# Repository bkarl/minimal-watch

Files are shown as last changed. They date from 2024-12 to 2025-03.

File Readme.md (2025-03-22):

# minimal-watch
This repo contains hardware and software for a minimalistic smartwatch. 

## Design goals

* step counter
* battery life of >= one year
* NFC data exchange
* powered by a coin cell
* fits a Casio F-91 W housing
* binary or hex time display using 12 bicolor LEDs
* brightness sensor to dim LEDs

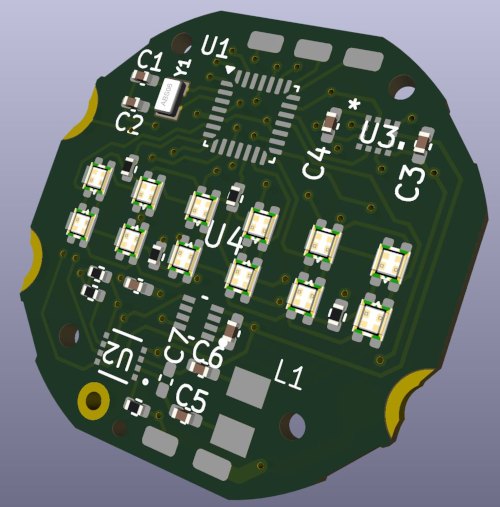
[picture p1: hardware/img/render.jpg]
minimal-watch


## Issues in hw v0.0.1
* swapped SCL/SDA lines
* missing pull up on NFC interrupt line (BOOT0 does not have an internal pull up)
* wakeup sources (BMA400 or NFC) are not connected to WKUP pins so standby mode is not possible
* resistor for green LEDs is too large
* NFC antenna circuit is not working (coil had to be crafted by hand and glued to housing)

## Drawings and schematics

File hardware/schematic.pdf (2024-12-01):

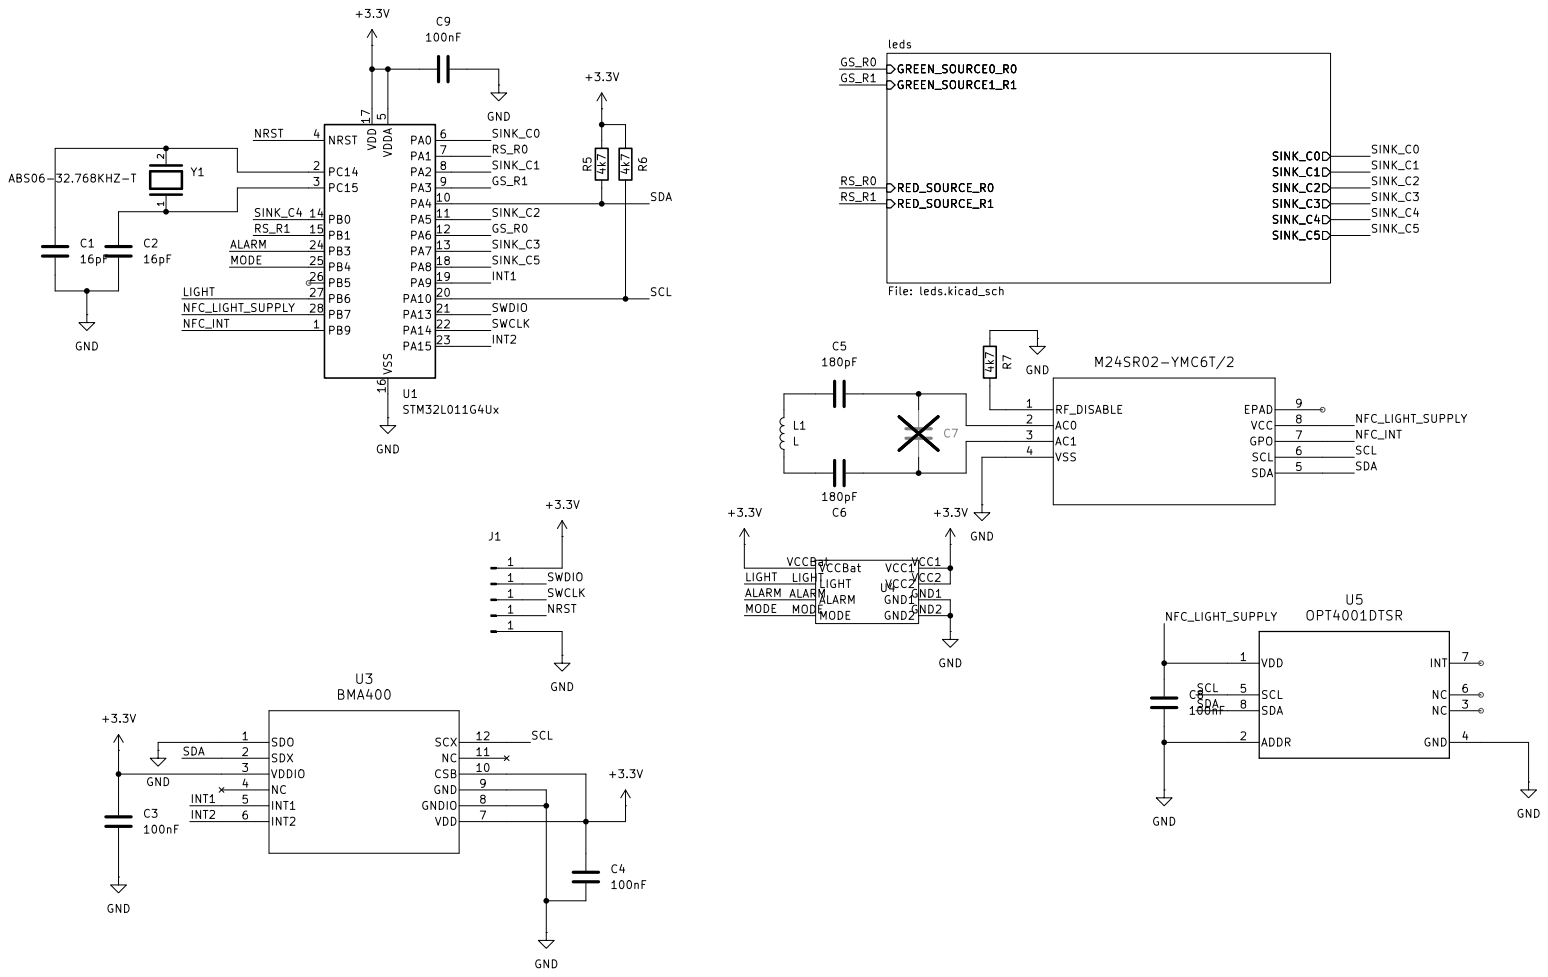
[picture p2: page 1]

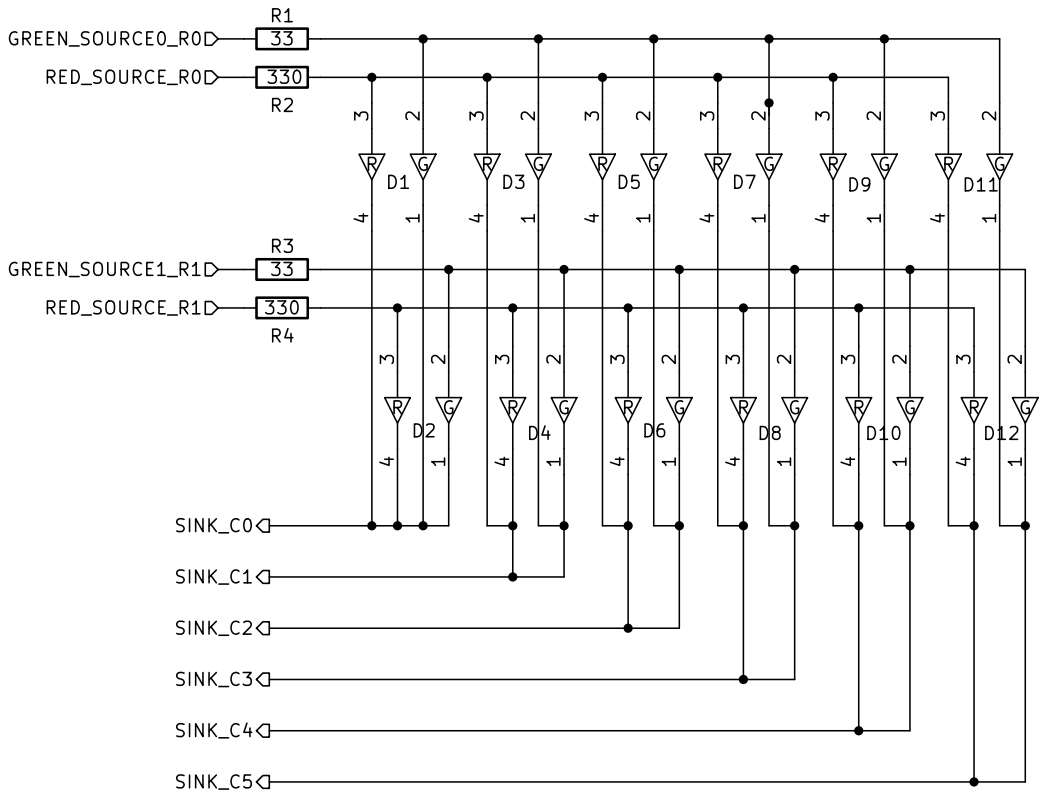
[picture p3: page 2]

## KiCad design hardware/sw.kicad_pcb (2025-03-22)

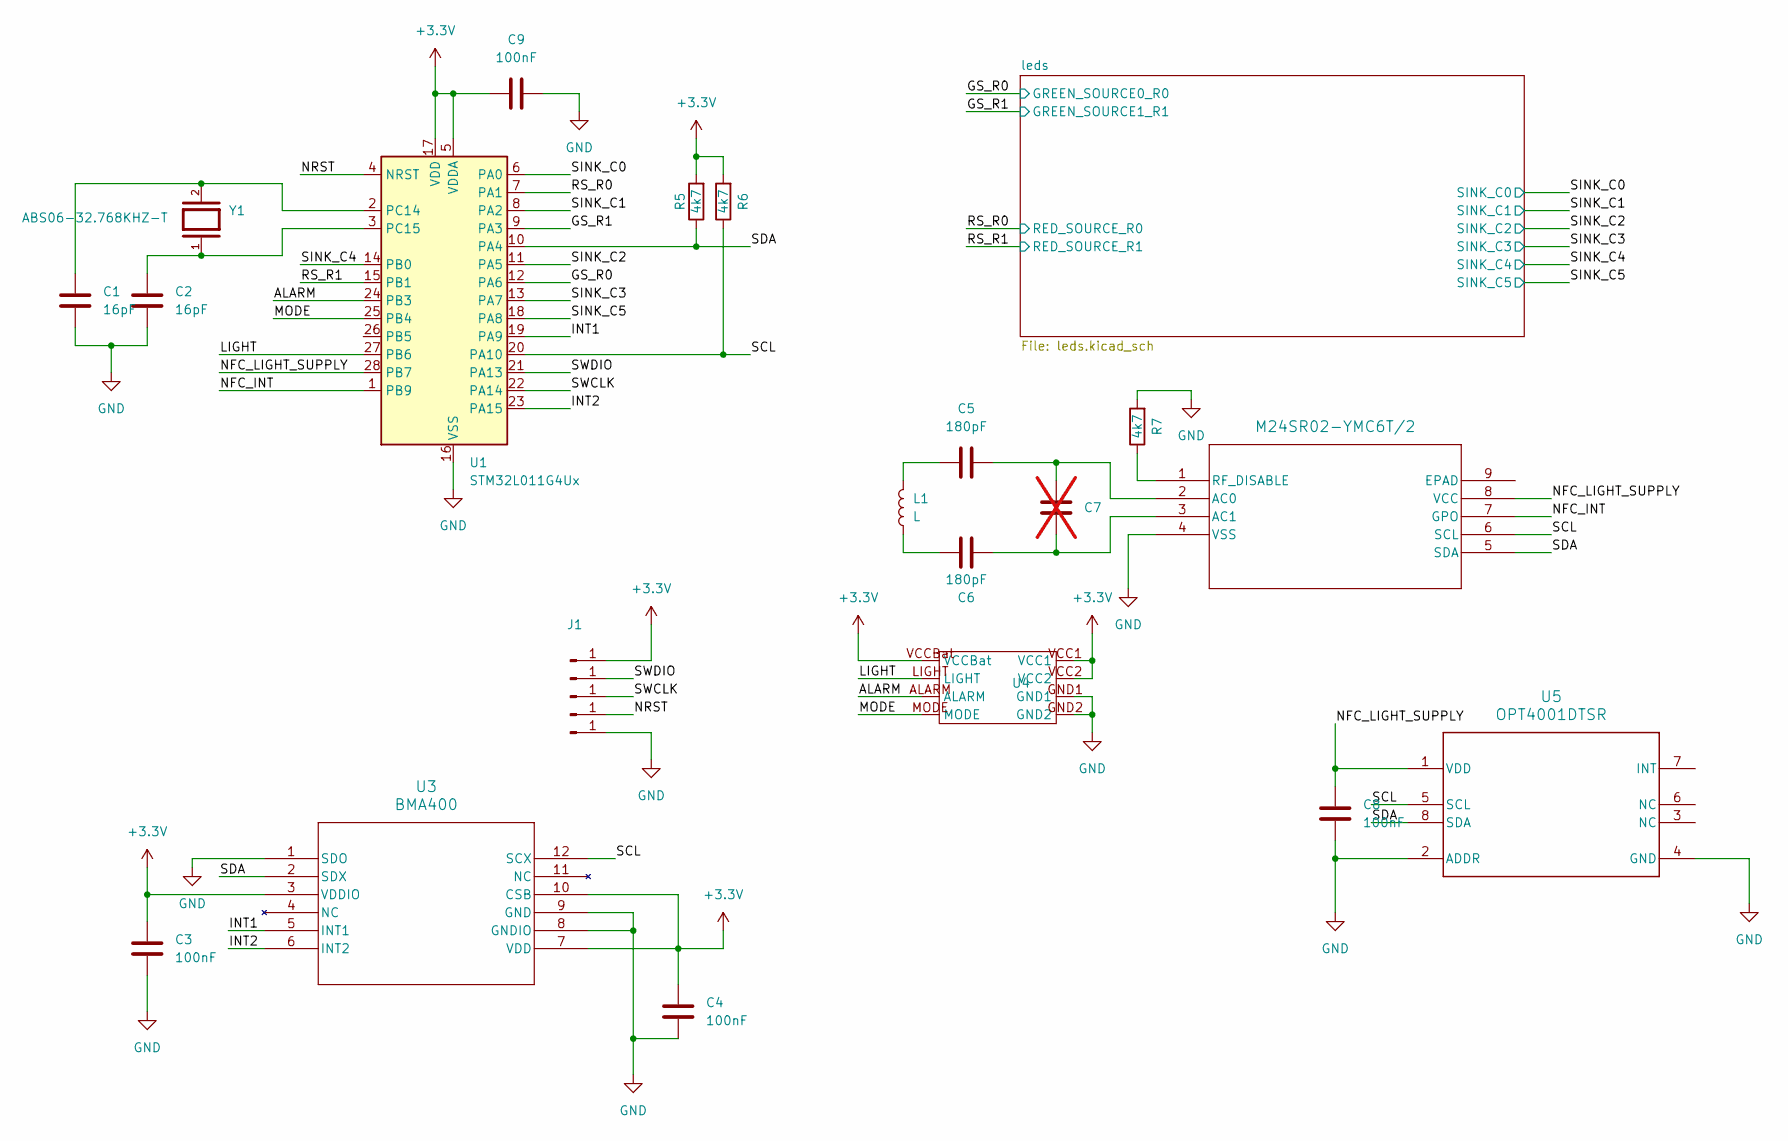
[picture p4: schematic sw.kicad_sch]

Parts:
C1, C2: 16pF; C_0402_1005Metric_Pad0.74x0.62mm_HandSolder
C3, C4, C8, C9: 100nF; C_0402_1005Metric_Pad0.74x0.62mm_HandSolder
C5, C6: 180pF; C_0402_1005Metric_Pad0.74x0.62mm_HandSolder
C7: C_0402_1005Metric_Pad0.74x0.62mm_HandSolder; not fitted
J1, J2, J3, J4, J5: Conn_01x01_Pin; SolderWirePad_1x01_SMD_1x2mm
L1: L; AANI-CH-0029
R5, R6, R7: 4k7; R_0402_1005Metric
U1: STM32L011G4Ux; QFN-28_4x4mm_P0.5mm
U2: M24SR02-YMC6T/2; UFDFPN8_M24SR02_STM
U3: BMA400; QFN_BMA400_BOS
U4: CASIO-F91W-OUTLINE-USB
U5: OPT4001DTSR; DTS0008A-MFG
Y1: ABS06-32.768KHZ-T; XTAL_ABS06-32.768KHZ-T; PARTREV 4/25/2022

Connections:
+3.3V: C3.1, C4.1, C9.1, J1.1, R5.2, R6.2, U1.5 (VDDA), U1.17 (VDD), U3.3 (VDDIO), U3.7 (VDD), U3.10 (CSB), U4.VCC1, U4.VCC2, U4.VCCBat
/ALARM: U1.24 (PB3), U4.ALARM
/GS_R0: U1.12 (PA6); also elsewhere on the board
/GS_R1: U1.9 (PA3); also elsewhere on the board
/INT1: U1.19 (PA9), U3.5 (INT1)
/INT2: U1.23 (PA15), U3.6 (INT2)
/LIGHT: U1.27 (PB6), U4.LIGHT
/MODE: U1.25 (PB4), U4.MODE
/NFC_INT: U1.1 (PB9), U2.7 (GPO)
/NFC_LIGHT_SUPPLY: C8.1, U1.28 (PB7), U2.8 (VCC), U5.1 (VDD)
/NRST: J4.1, U1.4 (NRST)
/RS_R0: U1.7 (PA1); also elsewhere on the board
/RS_R1: U1.15 (PB1); also elsewhere on the board
/SCL: R6.1, U1.20 (PA10), U2.6 (SCL), U3.12 (SCX), U5.5 (SCL)
/SDA: R5.1, U1.10 (PA4), U2.5 (SDA), U3.2 (SDX), U5.8 (SDA)
/SINK_C0: U1.6 (PA0); also elsewhere on the board
/SINK_C1: U1.8 (PA2); also elsewhere on the board
/SINK_C2: U1.11 (PA5); also elsewhere on the board
/SINK_C3: U1.13 (PA7); also elsewhere on the board
/SINK_C4: U1.14 (PB0); also elsewhere on the board
/SINK_C5: U1.18 (PA8); also elsewhere on the board
/SWCLK: J3.1, U1.22 (PA14)
/SWDIO: J2.1, U1.21 (PA13)
GND: C1.1, C2.2, C3.2, C4.2, C8.2, C9.2, J5.1, R7.2, U1.16 (VSS), U2.4 (VSS), U3.1 (SDO), U3.8 (GNDIO), U3.9 (GND), U4.GND1, U4.GND2, U5.2 (ADDR), U5.4 (GND)
unnamed: C5.1, L1.2
unnamed: C6.1, L1.1
unnamed: C1.2, U1.2 (PC14), Y1.2
unnamed: C2.1, U1.3 (PC15), Y1.1
unnamed: C5.2, C7.2, U2.2 (AC0)
unnamed: C6.2, C7.1, U2.3 (AC1)
unnamed: R7.1, U2.1 (RF_DISABLE)

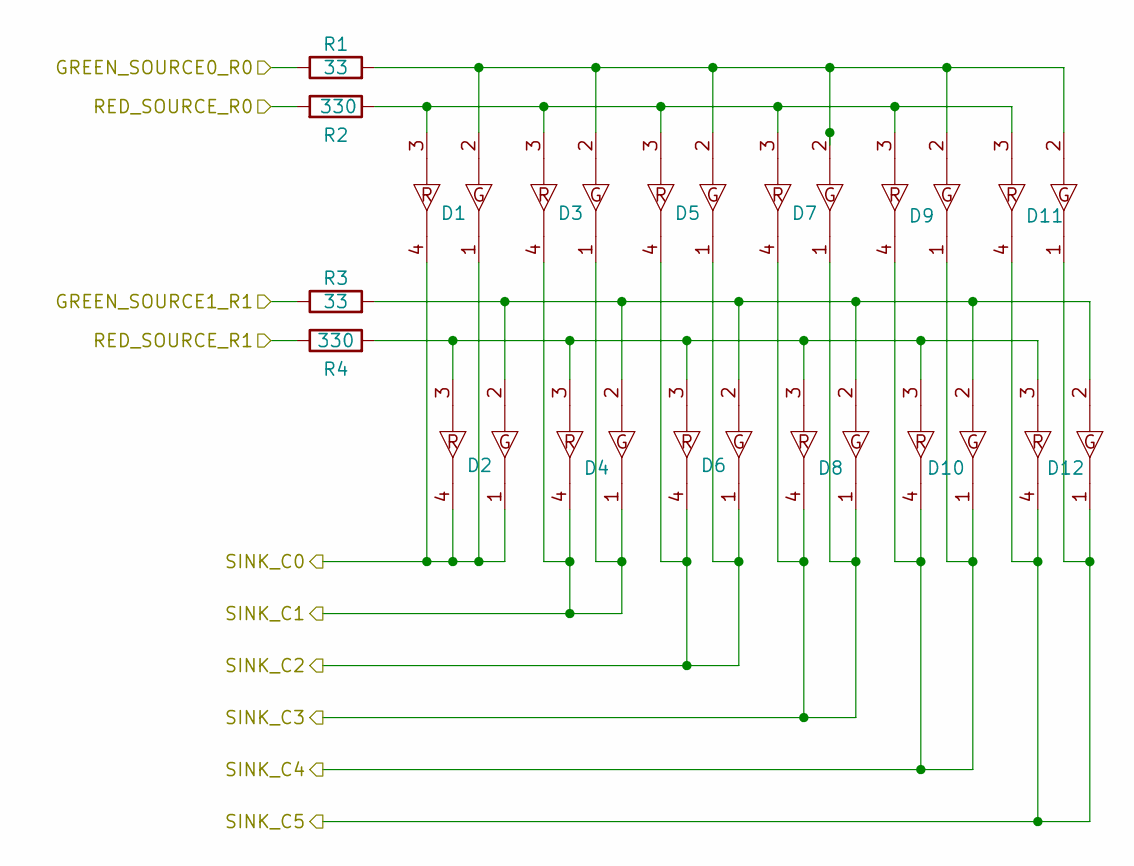
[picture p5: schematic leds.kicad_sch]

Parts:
D1, D2, D3, D4, D5, D6, D7, D8, D9, D10, D11, D12: WL-SBCD_150066RG54050
R1, R3: 33; R_0402_1005Metric
R2, R4: 330; R_0402_1005Metric

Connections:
/GS_R0: R1.1; also elsewhere on the board
/GS_R1: R3.1; also elsewhere on the board
/RS_R0: R2.2; also elsewhere on the board
/RS_R1: R4.1; also elsewhere on the board
/SINK_C0: D1.1, D1.4, D2.1, D2.4; also elsewhere on the board
/SINK_C1: D3.1, D3.4, D4.1, D4.4; also elsewhere on the board
/SINK_C2: D5.1, D5.4, D6.1, D6.4; also elsewhere on the board
/SINK_C3: D7.1, D7.4, D8.1, D8.4; also elsewhere on the board
/SINK_C4: D9.1, D9.4, D10.1, D10.4; also elsewhere on the board
/SINK_C5: D11.1, D11.4, D12.1, D12.4; also elsewhere on the board
unnamed: D1.2, D3.2, D5.2, D7.2, D9.2, D11.2, R1.2
unnamed: D1.3, D3.3, D5.3, D7.3, D9.3, D11.3, R2.1
unnamed: D2.2, D4.2, D6.2, D8.2, D10.2, D12.2, R3.2
unnamed: D2.3, D4.3, D6.3, D8.3, D10.3, D12.3, R4.2

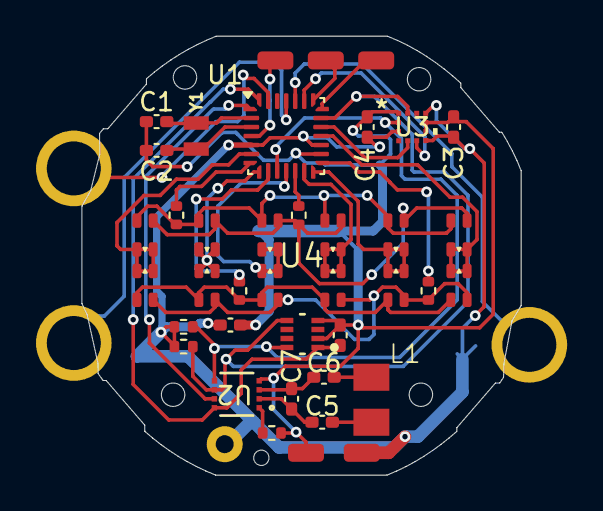
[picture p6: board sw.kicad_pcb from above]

Board: 2 copper layers, 24.4 x 24.4 mm, 40 parts (0 on the bottom side), 35 nets.

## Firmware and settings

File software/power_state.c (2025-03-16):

#include "power_state.h"
#include "settings.h"

volatile bool enter_sleep_mode = false;

void power_enter_stop_mode()
{
    //power_deinit_gpios();

    /*
    RCC_OscInitTypeDef RCC_OscInitStruct = {0};
    RCC_OscInitStruct.OscillatorType = RCC_OSCILLATORTYPE_LSE;
    RCC_OscInitStruct.LSEState = RCC_LSE_ON;
    if (HAL_RCC_OscConfig(&RCC_OscInitStruct) != HAL_OK)
    {
      Error_Handler();
    }
    */
    __HAL_PWR_CLEAR_FLAG(PWR_FLAG_WU);
    HAL_SuspendTick();
    HAL_PWR_EnterSTOPMode(PWR_LOWPOWERREGULATOR_ON, PWR_STOPENTRY_WFI);
}

void power_enable_light_nfc() {
  __HAL_RCC_GPIOB_CLK_ENABLE();

  GPIO_InitTypeDef GPIO_InitStruct = {0};

  GPIO_InitStruct.Pin = GPIO_PIN_NFC_LIGHTSENSOR_SUPPLY;
  GPIO_InitStruct.Mode = GPIO_MODE_OUTPUT_PP;
  GPIO_InitStruct.Speed = GPIO_SPEED_FREQ_VERY_HIGH;
  GPIO_InitStruct.Pull = GPIO_NOPULL;
  HAL_GPIO_Init(GPIO_PORT_NFC_LIGHTSENSOR_SUPPLY, &GPIO_InitStruct);
  HAL_GPIO_WritePin(GPIO_PORT_NFC_LIGHTSENSOR_SUPPLY, GPIO_PIN_NFC_LIGHTSENSOR_SUPPLY, GPIO_PIN_SET);
}

void power_disable_light_nfc() {
  __HAL_RCC_GPIOB_CLK_ENABLE();

  GPIO_InitTypeDef GPIO_InitStruct = {0};

  GPIO_InitStruct.Pin = GPIO_PIN_NFC_LIGHTSENSOR_SUPPLY;
  GPIO_InitStruct.Mode = GPIO_MODE_OUTPUT_PP;
  GPIO_InitStruct.Speed = GPIO_SPEED_FREQ_VERY_HIGH;
  GPIO_InitStruct.Pull = GPIO_NOPULL;
  HAL_GPIO_Init(GPIO_PORT_NFC_LIGHTSENSOR_SUPPLY, &GPIO_InitStruct);
  HAL_GPIO_WritePin(GPIO_PORT_NFC_LIGHTSENSOR_SUPPLY, GPIO_PIN_NFC_LIGHTSENSOR_SUPPLY, GPIO_PIN_RESET);
}

void power_leave_stop_mode()
{
  HAL_ResumeTick();
  enter_sleep_mode = false;
}

void power_deinit_gpios() {
  GPIO_InitTypeDef GPIO_InitStruct = {0};

  __HAL_RCC_GPIOB_CLK_ENABLE();
  __HAL_RCC_GPIOC_CLK_ENABLE();
  __HAL_RCC_GPIOA_CLK_ENABLE();

  GPIO_InitStruct.Pin = GPIO_PIN_All;
  GPIO_InitStruct.Mode = GPIO_MODE_ANALOG;
  GPIO_InitStruct.Speed = GPIO_SPEED_FREQ_VERY_HIGH;
  GPIO_InitStruct.Pull = GPIO_NOPULL;
  HAL_GPIO_Init(GPIOB, &GPIO_InitStruct);
  HAL_GPIO_Init(GPIOA, &GPIO_InitStruct);

  __HAL_RCC_GPIOA_CLK_DISABLE();
  __HAL_RCC_GPIOB_CLK_DISABLE();
  __HAL_RCC_GPIOC_CLK_DISABLE();
}

void power_init_timeout_counter() {
  __HAL_RCC_LPTIM1_CLK_ENABLE();

  HAL_NVIC_SetPriority(LPTIM1_IRQn, 0, 0);
  HAL_NVIC_EnableIRQ(LPTIM1_IRQn);
  LPTIM1->CR = 0;
  LPTIM1->IER = LPTIM_IER_CMPMIE;
  LPTIM1->CFGR = LPTIM_CFGR_PRESC;
  LPTIM1->CR = LPTIM_CR_ENABLE;
  LPTIM1->ARR = (32768 / 128) * DISPLAY_TIMEOUT_SECONDS + 1;
  LPTIM1->CMP = (32768 / 128) * DISPLAY_TIMEOUT_SECONDS;
  LPTIM1->CR = LPTIM_CR_ENABLE | LPTIM_CR_CNTSTRT;
}

void power_stop_timeout_counter() {
  LPTIM1->CR = 0;
  __HAL_RCC_LPTIM1_CLK_DISABLE();
}

void power_reset_timeout_counter() {
  LPTIM1->CR = 0;
  LPTIM1->CR = LPTIM_CR_ENABLE | LPTIM_CR_CNTSTRT;
}

void power_timeout_counter_elapsed()
{
  power_stop_timeout_counter();
  enter_sleep_mode = true;
}

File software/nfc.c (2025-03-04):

#include "nfc.h"
#include "power_state.h"

void nfc_copy_step_ctr_payload(uint8_t *dst_buffer, RTC_DateTypeDef *sDate, uint32_t n_steps);
void nfc_write_data_to_memory(uint8_t *data, uint8_t offset, uint8_t len);
void nfc_set_int_to_wip_mode();

void init_nfc() {
    power_enable_light_nfc();
    uint8_t rdata_out[255];
    c_apdu_r response = {
        .data = rdata_out
    };

    uint8_t data[] = {0xD2, 0x76, 0x00, 0x00, 0x85, 0x01, 0x01};
    c_apdu_t select_ndef_tag_application = {
        .PCB = NFC_PCB_BYTE,
        .CLA = 0,
        .INS = NFC_INS_SELECT_FILE,
        .P1 = 0x04,
        .P2 = 0x00,
        .LC = 0x07,
        .data = data,
        .LE = 0
    };

    uint8_t data_ndef_select[] = {0x00, 0x01};

    c_apdu_t select_ndef_file = {
        .PCB = NFC_PCB_BYTE,
        .CLA = 0,
        .INS = NFC_INS_SELECT_FILE,
        .P1 = 0x00,
        .P2 = 0x0C,
        .LC = 0x02,
        .data = data_ndef_select,
        .LE = 0
    };

    nfc_init_crc_engine();
    do {
        i2c_write_register(NFC_ADDRESS, NFC_GET_I2C_SESSION, NULL, 0);

        HAL_Delay(NFC_WAIT_MS_AFTER_CMD);

        nfc_send_apdu_p(&select_ndef_tag_application, true);
        nfc_read_apdu_r(&response, select_ndef_tag_application.LE);
    } while (response.SW1 != 0x90);

    //nfc_set_int_to_wip_mode();

    nfc_send_apdu_p(&select_ndef_file, false);
    nfc_read_apdu_r(&response, select_ndef_file.LE);
}

void nfc_set_int_to_wip_mode() {
    c_apdu_r response;

    uint8_t data_ndef_select[] = {0xE1, 0x01};

    c_apdu_t select_system_file = {
        .PCB = NFC_PCB_BYTE,
        .CLA = 0,
        .INS = NFC_INS_SELECT_FILE,
        .P1 = 0x00,
        .P2 = 0x0C,
        .LC = 0x02,
        .data = data_ndef_select,
        .LE = 0
    };

    nfc_send_apdu_p(&select_system_file, false);
    nfc_read_apdu_r(&response, select_system_file.LE);

    uint8_t system_file[0x11];
    nfc_read_data_from_memory(system_file, 0, sizeof(system_file));

    uint8_t pw[16] = {0};

    c_apdu_t verify_file = {
        .PCB = NFC_PCB_BYTE,
        .CLA = 0,
        .INS = 0x20,
        .P1 = 0x00,
        .P2 = 0x03,
        .LC = 0x10,
        .data = pw,
        .LE = 0
    };

    nfc_send_apdu_p(&verify_file, false);
    nfc_read_apdu_r(&response, verify_file.LE);

    uint8_t gpo_byte = 0x30;
    nfc_write_data_to_memory(&gpo_byte, 4, 1);
    nfc_read_data_from_memory(&gpo_byte, 4, 1);
    
    return;
}

void deinit_nfc() {
    power_disable_light_nfc();
}

uint8_t nfc_read_total_ndef_length() {
    uint8_t len[2];

    nfc_read_data_from_memory(len, 0, sizeof(len));
    uint8_t total_len = len[1];
    return total_len;
}

void nfc_read_data_from_memory(uint8_t *dst, uint8_t offset, uint8_t len) {
    c_apdu_r response = {.data = dst};

    c_apdu_t read_binary = {
        .PCB = NFC_PCB_BYTE,
        .CLA = 0,
        .INS = NFC_INS_READ_BINARY,
        .P1 = 0x00,
        .P2 = offset,
        .LC = 0x00,
        .data = 0,
        .LE = len
    };

    nfc_send_apdu_p(&read_binary, true);
    nfc_read_apdu_r(&response, read_binary.LE);
    return;
}


bool nfc_read_timestamp_record(RTC_TimeTypeDef *sTime, RTC_DateTypeDef *sDate) {
    uint8_t rdata_out[255];

    c_apdu_r response = {
        .data = rdata_out
    };

    c_apdu_t read_binary = {
        .PCB = NFC_PCB_BYTE,
        .CLA = 0,
        .INS = NFC_INS_READ_BINARY,
        .P1 = 0x00,
        .P2 = 0x02,
        .LC = 0x00,
        .data = 0,
        .LE = 0x02
    };

    uint8_t total_len = nfc_read_total_ndef_length();

    if (total_len > NFC_STEP_RECORD_MIN_LENGTH || total_len == 0)
        return false;

    read_binary.P2 = 2;
    read_binary.LE = total_len;

    nfc_send_apdu_p(&read_binary, true);
    nfc_read_apdu_r(&response, read_binary.LE);
    external_type_ndef_record_t *timestamp_record = (external_type_ndef_record_t*)response.data;
    size_t offset_to_payload = timestamp_record->type_len + NUM_HEADER_BYTES_IN_NFC_PAYLOAD;

    timestamp_record->payload = &response.data[offset_to_payload];
    sDate->Year = timestamp_record->payload[OFFSET_TO_YEAR];
    sDate->Month = timestamp_record->payload[OFFSET_TO_MONTH];
    sDate->Date = timestamp_record->payload[OFFSET_TO_DAY];
    sTime->Hours = timestamp_record->payload[OFFSET_TO_HOUR];
    sTime->Minutes = timestamp_record->payload[OFFSET_TO_MINUTE];
    sTime->Seconds = timestamp_record->payload[OFFSET_TO_SECOND];

    return true;
}

void nfc_update_step_ctr_record(RTC_DateTypeDef *sDate, uint32_t n_steps, bool append_new_record) {
    uint8_t total_len = nfc_read_total_ndef_length();

    uint8_t full_msg[100];
    nfc_read_data_from_memory(full_msg, 2, total_len);

    if (total_len < NFC_STEP_RECORD_MIN_LENGTH) {
        nfc_write_step_ctr_message(sDate, n_steps);
        return;
    }

    uint8_t new_size = total_len + STEP_CTR_RECORD_SIZE_BYTES;
    uint8_t new_payload_len;
    uint8_t new_record[STEP_CTR_RECORD_SIZE_BYTES];
    uint8_t write_offset = total_len;

    if (!append_new_record)
        write_offset -= STEP_CTR_RECORD_SIZE_BYTES;

    nfc_read_data_from_memory(&new_payload_len, NFC_OFFSET_TO_NDEF_STEPS_PAYLOAD_LEN, 1);
    new_payload_len += STEP_CTR_RECORD_SIZE_BYTES;
    nfc_copy_step_ctr_payload(new_record, sDate, n_steps);
    nfc_clear_ndef_message();
    nfc_write_data_to_memory(new_record, write_offset + NFC_OFFSET_TO_NDEF_MESSAGE, STEP_CTR_RECORD_SIZE_BYTES);

    if (append_new_record) {
        nfc_write_data_to_memory(&new_payload_len, NFC_OFFSET_TO_NDEF_STEPS_PAYLOAD_LEN, 1);
        nfc_write_data_to_memory(&new_size, 1, 1);
    }
}

void nfc_write_data_to_memory(uint8_t *data, uint8_t offset, uint8_t len) {
    c_apdu_r response;
    //static uint8_t block_number = 0x00;
    c_apdu_t update_binary = {
        .PCB = NFC_PCB_BYTE,
        .CLA = 0,
        .INS = NFC_INS_UPDATE_BINARY,
        .P1 = 0x00,
        .P2 = 0,
        .LC = 0,
        .data = 0,
        .LE = 0
    };

    //block_number ^= 1;
    uint8_t n_bytes_written = 0;
    uint8_t current_address = offset;

    //https://community.st.com/t5/st25-nfc-rfid-tags-and-readers/m24sr64-we-can-only-write-to-the-ndef-file-within-16-byte-blocks/
    while(n_bytes_written < len) {
        uint8_t n_bytes_to_write = 16 - (current_address % 16);
        uint8_t remaining_bytes_to_write = len - n_bytes_written;
        if (n_bytes_to_write > remaining_bytes_to_write)
            n_bytes_to_write = remaining_bytes_to_write;

        update_binary.P2 = current_address;
        update_binary.LC = n_bytes_to_write;
        update_binary.data = data + n_bytes_written;

        nfc_send_apdu_p(&update_binary, false);
        nfc_read_apdu_r(&response, update_binary.LE);

        current_address += n_bytes_to_write;
        n_bytes_written += n_bytes_to_write;
    }
}

void nfc_clear_ndef_message() {
    uint8_t len_field[2] = {0};
    nfc_write_data_to_memory(len_field, 0, sizeof(len_field));
}
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

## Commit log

2024-12-21 added i2c bitbanging code
2024-12-25 added interrupt code
2025-01-03 fix i2c
2025-01-05 added timer to enter stop mode
2025-01-26 removed hal timer code
2025-02-05 wip state handling, enable i2c internal pull ups
2025-02-15 added sceond alarm, stage handling
2025-03-03 enable wip interrupt
2025-03-22 added kicad data
    [leds.kicad_sch, sw.kicad_pcb, sw.kicad_sch]
2025-03-22 keep track of issues
